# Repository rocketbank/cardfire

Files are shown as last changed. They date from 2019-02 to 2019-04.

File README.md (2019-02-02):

# pan-scanner
Сканит PAN карты и вводит притворяясь клавиатурой

[Все в Notion ](https://www.notion.so/rocketguys/CardFire-PAN-Scanner-b663bdf931e24fb18de7a37c51332b52)

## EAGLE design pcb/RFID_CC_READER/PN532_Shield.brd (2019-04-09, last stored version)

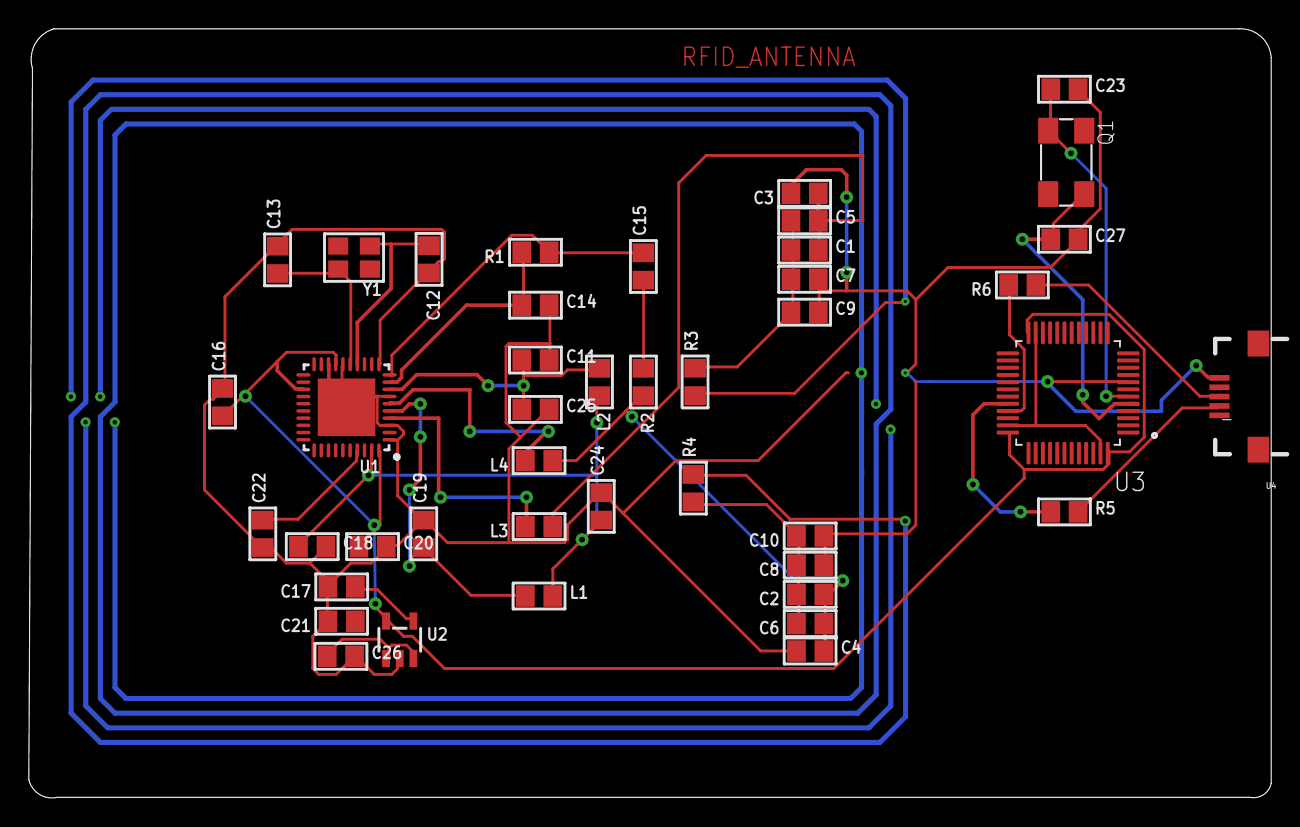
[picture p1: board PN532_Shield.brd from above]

Board: 2 copper layers, 86.2 x 53.4 mm, 44 parts (0 on the bottom side), 29 nets.

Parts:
C1, C2: 22pF; 0805
C3, C4: 220pF; 0805
C5, C6, C9, C10: NC; 0805
C7, C8: 100pF; 0805
C11, C14, C16, C17, C20, C24: 0.1µF; 0805
C12, C13, C23, C27: 33pF; 0805
C15: 1000pF; 0805
C18, C19, C21, C22, C25, C26: 10µF; 0805
L1, L2: FERRITE; 0805
L3, L4: 560nH; 0805
L5: RFID_ANTENNA; ANTENNA
Q1: 6.0X3.5_4
R1, R5, R6: 1.0K; 0805
R2: 1.69K; 0805
R3, R4: 1.5; 0805
U1: PN532; HVQFN40-6X6
U2: ADP122(3.3V); SOT23-5
U3: STM32F103C8T6; QFP50P900X900X160-48N
U4: USB-MICRO-SMD
Y1: 27.12MHz; CRYSTAL_3.2X2.5

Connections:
5.0V: C26.1, U2.1, U2.3
GND: C4.1, C11.2, C12.2, C13.2, C14.2, C16.2, C17.2, C18.2, C19.2, C20.2, C21.2, C22.1, C24.2, C25.2, C26.2, U1.1, U1.3, U1.7, U1.11, U1.16, U1.18, U1.TP, U2.2
unnamed: L3.2, U1.4
unnamed: C1.2, C3.1, C5.2, L3.1
unnamed: L5.RIGHT_PIN, R3.1
unnamed: L5.LEFT_PIN, R4.2
unnamed: R5.1, U3.32
unnamed: C12.1, U1.14, Y1.1
unnamed: C13.1, U1.15, Y1.2
unnamed: C15.1, R2.1
unnamed: C14.1, R1.2, U1.9
unnamed: C15.2, R1.1, U1.10
unnamed: C2.1, C4.2, C6.1, L4.1, R2.2
unnamed: C11.1, C25.1, L2.1, U1.8
unnamed: C19.1, L1.1, U1.5
unnamed: R6.2, U3.33
unnamed: R5.2, U4.D-1
unnamed: R6.1, U4.D+1
unnamed: C27.1, Q1.3, U3.5
unnamed: C23.1, Q1.1, U3.6
unnamed: C17.1, U2.4
unnamed: C22.2, U1.37
S$1: C3.2, C7.2, C9.2, C23.2, C27.2
S$3: C8.1, C10.1
TX1_ANTENNA: C1.1, C5.1, C7.1, C9.1, R3.2
TX2_ANTENNA: C2.2, C6.2, C8.2, C10.2, R4.1
VCC: C18.1, C24.1, L1.2, L2.2, U1.39
VDD: C16.1, C20.1, U1.17, U1.23, U1.40, U2.5, U3.24, U3.36, U3.48
VSS: U3.23, U3.35, U3.47

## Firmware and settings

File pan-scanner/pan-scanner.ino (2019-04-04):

// #define DEBUG

// Beeper type
// #define ACTIVE

// PAN keyboard output mode
#define LAST4

#define PN532_SCK (2)
#define PN532_MOSI (3)
#define PN532_SS (4)
#define PN532_MISO (5)
#define LAST4

#define PN532_SCK (2)
#define PN532_MOSI (3)
#define PN532_SS (4)
#define PN532_MISO (5)

#ifdef DEBUG
#define MIFAREDEBUG
#define PN532DEBUG
#endif

#include <SPI.h>
#include <Adafruit_PN532.h>

#include <USBComposite.h>

USBHID HID;
HIDKeyboard Keyboard(HID);

Adafruit_PN532 nfc(PN532_SS);

void PrintPAN(const byte *data)
{
  uint32_t szPos = 5;
#ifdef LAST4
  szPos += (16 - 4) / 2;
#endif
  for (; szPos < 13; szPos++) // 8 итераций по 2 PAN-цифры в каждом числе за раз
  {
    // Append leading 0 for small values
    if (data[szPos] <= 0xF)
      Keyboard.print(F("0"));
    Keyboard.print(data[szPos], HEX);
  }
}

void Beep(unsigned int duration)
{
#ifdef ACTIVE
  digitalWrite(PB1, HIGH);
  delay(duration);
  digitalWrite(PB1, LOW);
#endif
#ifndef ACTIVE
  tone(PB1, 2400);
  delay(duration);
  analogWrite(PB1, 0);
#endif
}

// short-short
void BeepReady()
{
  Beep(100u);
  delay(100);
  Beep(100u);
}

// long-short-long
void BeepError()
{
  Beep(100u);
  delay(500);
  Beep(100u);
  delay(100);
  Beep(1000u);
}

void Debug(const char * str)
{
#ifdef DEBUG
  Keyboard.println(str);
  Serial.println(str);
#endif
}

void setup(void)
{
  Serial.begin(115200);

#ifdef DEBUG
  Serial.println("initializing...");
#endif

  HID.begin(HID_KEYBOARD);
  Keyboard.begin(); // useful to detect host capslock state and LEDs
  pinMode(PB1, OUTPUT); // BEEP_PIN
  //delay(1000);

  Debug("keyboard had initialized");
  nfc.begin();

  delay(1000);

  Debug("All (nfc, keyboard, serial, pins) had initialized");

  uint32_t versiondata = nfc.getFirmwareVersion();
  if (!versiondata)
  {
    Debug("Didn't find PN53x board");
    BeepError();
    while (1); // halt
  }

  Debug("Found chip");

  // Set the max number of retry attempts to read from a card
  // This prevents us from waiting forever for a card, which is
  // the default behaviour of the PN532.
  // 0xFF to wait forever, 0x00..0xFE to timeout after mxRetries
  nfc.setPassiveActivationRetries(0xFF);

  nfc.SAMConfig();
  // Keyboard.println("Waiting for an ISO14443A card");

  Debug("ready");

  BeepReady();
}

void loop(void)
{
  bool success;
  uint8_t SELECT_APPLICATION[] = {0x00, 0xA4, 0x04, 0x00, 0x07, 0xA0, 0x00, 0x00, 0x00, 0x04, 0x10, 0x10, 0x00};
  uint8_t GET_PROCESSING_OPTIONS[] = {0x80, 0xA8, 0x00, 0x00, 0x02, 0x83, 0x00, 0x00};
  uint8_t READ_RECORD[] = {0x00, 0xB2, 0x01, 0x14, 0x00};

  uint8_t response[64];
  uint8_t responseLength = sizeof(response);

  Debug(".");

  success = nfc.inListPassiveTarget();

  if (success)
  {
    Debug("Found something!");

    if (nfc.inDataExchange(SELECT_APPLICATION, sizeof(SELECT_APPLICATION), response, &responseLength))
    {
      //nfc.PrintHexChar(response, responseLength);
    }
    if (nfc.inDataExchange(GET_PROCESSING_OPTIONS, sizeof(GET_PROCESSING_OPTIONS), response, &responseLength))
    {
      //nfc.PrintHexChar(response, responseLength);
    }
    if (nfc.inDataExchange(READ_RECORD, sizeof(READ_RECORD), response, &responseLength))
    {
      //nfc.PrintHexChar(response, responseLength); // Ничего не печатает
      PrintPAN(response);
      Keyboard.println("");
      Beep(100u);
      // delay(1000);
    }
  }

  else
  {
    //              Keyboard.println("Timed out waiting for a card");
  }
}

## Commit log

2019-02-04 Create preferences.txt (#1)
    You can copy-paste it to
    ~/Library/Arduino15/preferences.txt
    may be...
2019-03-22 fixes + passive beeper
    [pan-scanner.ino]
2019-04-04 pcb wip
    [PN532_Shield.brd, PN532_Shield.sch]
2019-04-09 library updates
    [PN532_Shield.brd, PN532_Shield.sch]

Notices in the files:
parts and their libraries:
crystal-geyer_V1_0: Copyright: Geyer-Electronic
